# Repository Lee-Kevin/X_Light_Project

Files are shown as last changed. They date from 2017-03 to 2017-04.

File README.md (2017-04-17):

# RGBLED_Ligh Controller Hardware Part
For this project, the hardware part is very import, We buy a RGB bulb from Huaqiang North in ShenZhen, it's something just like below picture shows.

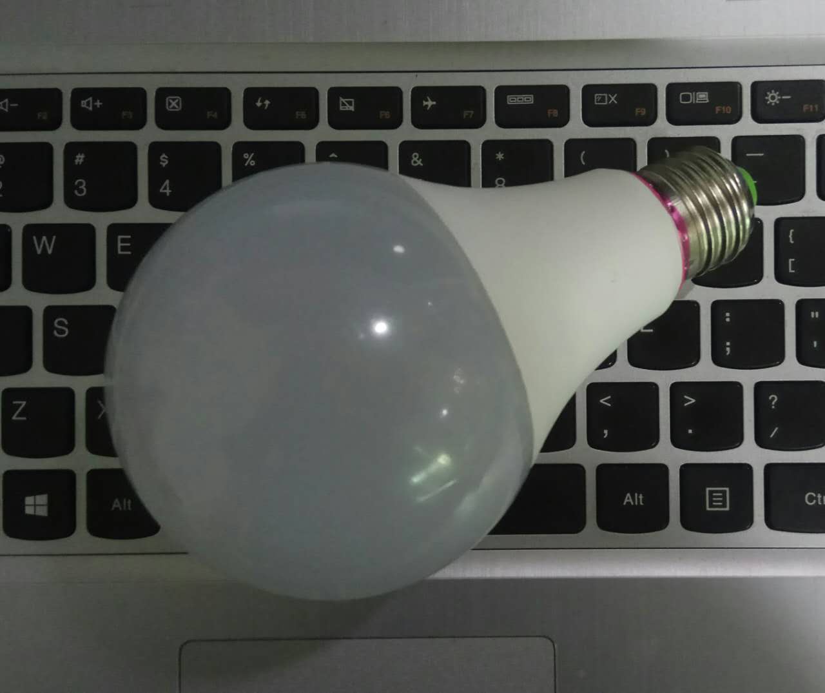
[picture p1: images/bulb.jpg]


The factory version of the bulb is controlled by an IR Remote controller, for this project, we want to control the bulbs by group or control each bulb independently. So we did a special pcb for this bulb. Just like below picture shows.

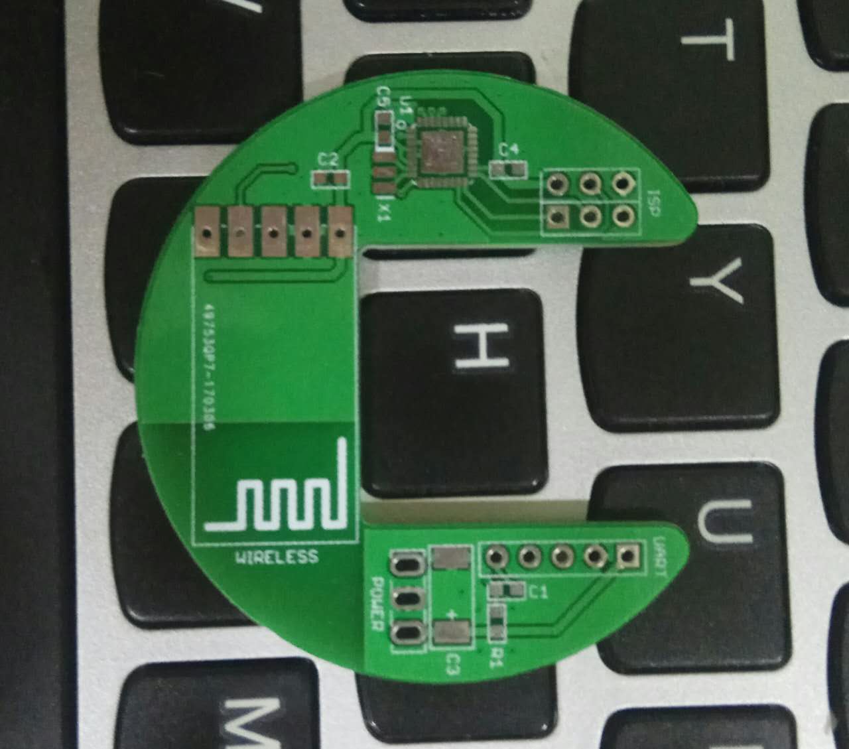
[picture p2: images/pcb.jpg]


I remove the IR reciver from the factory version, and connect the original IR Reciver Pin to the new board, After assembling the bulb is just as shown in the following figure.

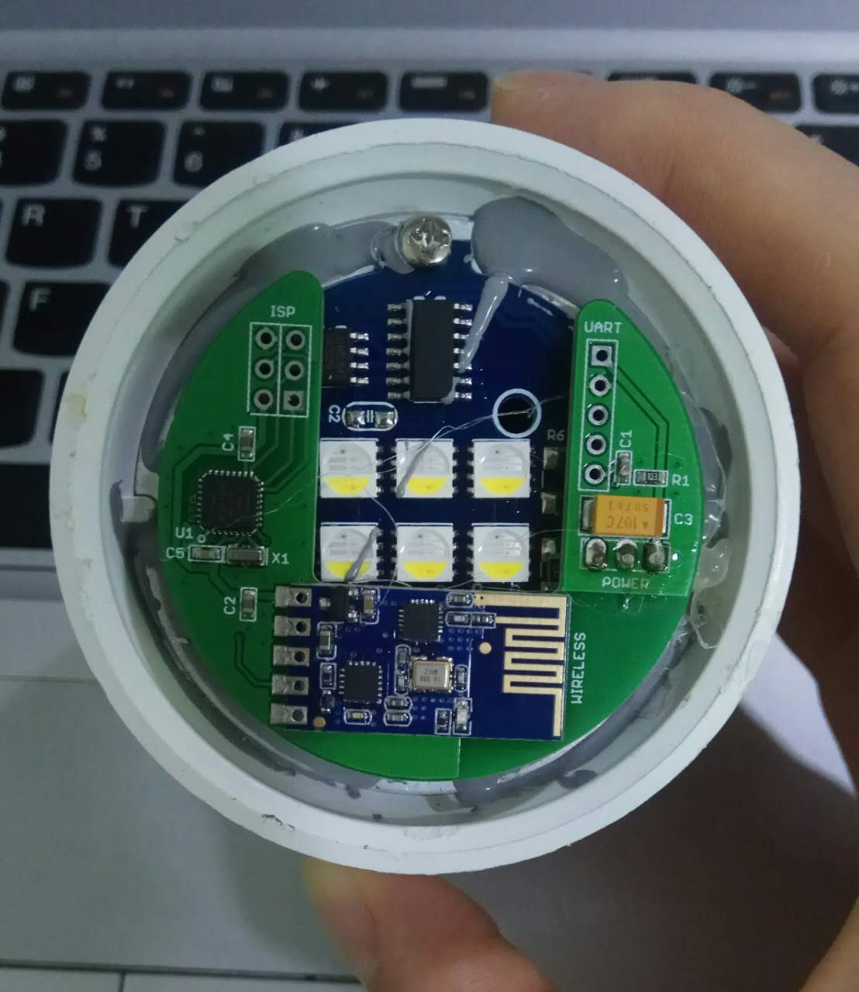
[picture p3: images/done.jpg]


About the pcb and the schematic file, you can click **[here](https://github.com/Lee-Kevin/X_Light_Project/tree/master/Hardware)** to download.

# RGBLED_Ligh Controller Software Part
------
In this project, the software has two part, one is the slave part and the another one is master part.

The slave part will connect to a RGB light, and control the color of the light, the communication between slave and master is wireless/RF.

## Slave Part

This part will recive the command from the master part.

The data frame is:

Head  -  Address  -  Command  -  End

0xAA  -    Addr   -  Command  -  0x55

The Address is a uint8_t value range from 0~255, and 255 is the boardcast address, and 0 is a reserved address.

The Command is something like this:
``` C 
enum LEDstatus {
    led_on            = 0,
    led_off           = 1,
    led_down          = 2,
    led_up            = 3,
    led_red           = 4,
    led_green         = 5,
    led_blue          = 6,
    led_white         = 7,
    led_lightSalmon   = 8,
    led_orangeRed     = 9,
    led_orange        = 10,
    led_yellow        = 11,
    led_paleGreen     = 12,
    led_skyBlue       = 13,
    led_turquoise     = 14,
    led_royalBlue     = 15,
    led_steelBlue     = 16,
    led_purple        = 17,
    led_rebeccapurple = 18,
    led_orchid        = 19,
    led_flash         = 20,
    led_strobe        = 21,
    led_fade          = 22,
    led_smooth        = 23,
    
};
typedef enum LEDstatus ledstatus_t;
ledstatus_t eLEDStatus;
```

The slave part can also set the address via UART, and the command data is like this:

Head  --  Addr  --  Command  -- New Addr  --  END

0xAA  --  0xFF  --   0xFF    --  New Addr --  0x55

Then you can also get the slave address by send the following command:

Head  --  Addr  --  Command  --  END

0xAA  --  0xFF  --   0xFE    --  0x55

Note: the 0xFF is the boardcast addr.

## Master Part

For this system, there can be many master parts to control the light, the only thing that master part need to do is sending commands.

The Master part1 is used for sending command to the slave part, and this part has the following functions.
1. Recive IR command from the IR controller.
2. Recive comand from the computer(just recive data from uart,and send it out via software serial).
3. Change the display mode by a button.
4. Turn ON/OFF the light by a button

More master part to be continued.

## The Light Number 

The following picture shows how the Light is arrranged.

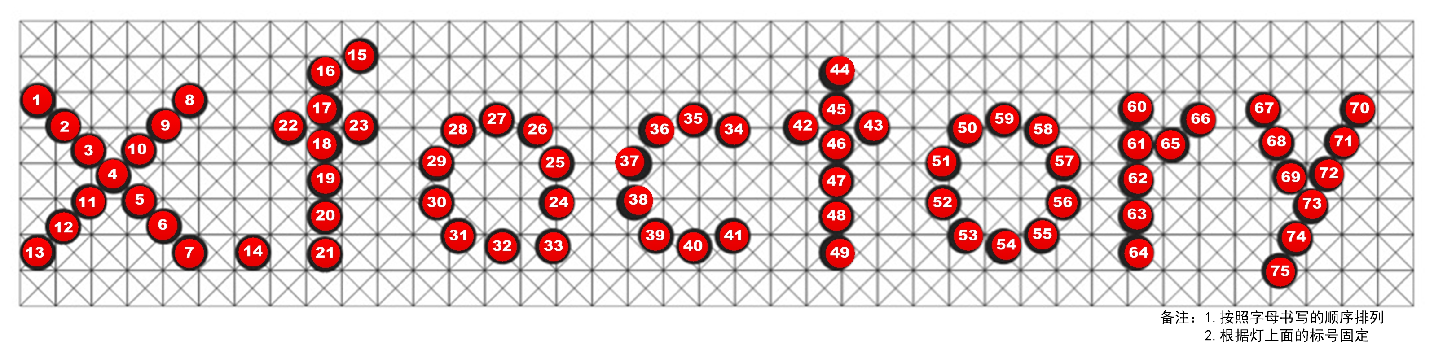
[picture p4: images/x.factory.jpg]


## The finished work

to be continued

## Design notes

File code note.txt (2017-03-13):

=================================================================================================================

1. LightControl_Slave - 201702280948  完成基本程序框架，下一步能够发送指令  9:51 2017/2/28
2. LightControl_Slave - 201702281410  完成指令控制功能，下一步，可以修改地址，并把地址信息写入EEPROM
3. LightControl_Slave - 201703011250  完成software serial的使用，下一步，通过UART可以修改地址 13:39 2017/3/1
4. LightControl_Slave - 201703021253  可以通过串口访问并修改地址，从机程序基本完成 12:54 2017/3/2
5. LightControl_Slave - 201703021726  修正开灯的红外编码 17:26 2017/3/2
6. LightControl_Slave - 201703091451  缩短看门狗喂狗时间至200ms, 添加数据发送临界保护

=================================================================================================================

1. LightControl_Master - 201703021727 完成红外控制广播和串口透传，下一步添加led bar 驱动。
2. LightControl_Master - 201703072201 完成OLED的添加，并显示每一种模式的提示，下一步，增加button, 用button，切换显示模式
3. LightControl_Master - 201703081221 添加了一个button, 用来控制灯的开关，下一步，增加另外另个button，用来切换模式。
4. LightControl_Master - 201703081555 添加了其它两个button，现在出现莫名重启情况，需要研究下原因
5. LightControl_Master - 201703081916 用按键查询方法解决了重启问题，但是在写模式时，关灯指令有时不能响应，需要研究一下原因
6. LightControl_Master - 201703092025 上述问题通过修改从机端代码解决，现在增加了on/off界面，下一步，完善命令发射函数，尽量多写几个模式
7. LightControl_Master - 201703111126 完成4种模式效果

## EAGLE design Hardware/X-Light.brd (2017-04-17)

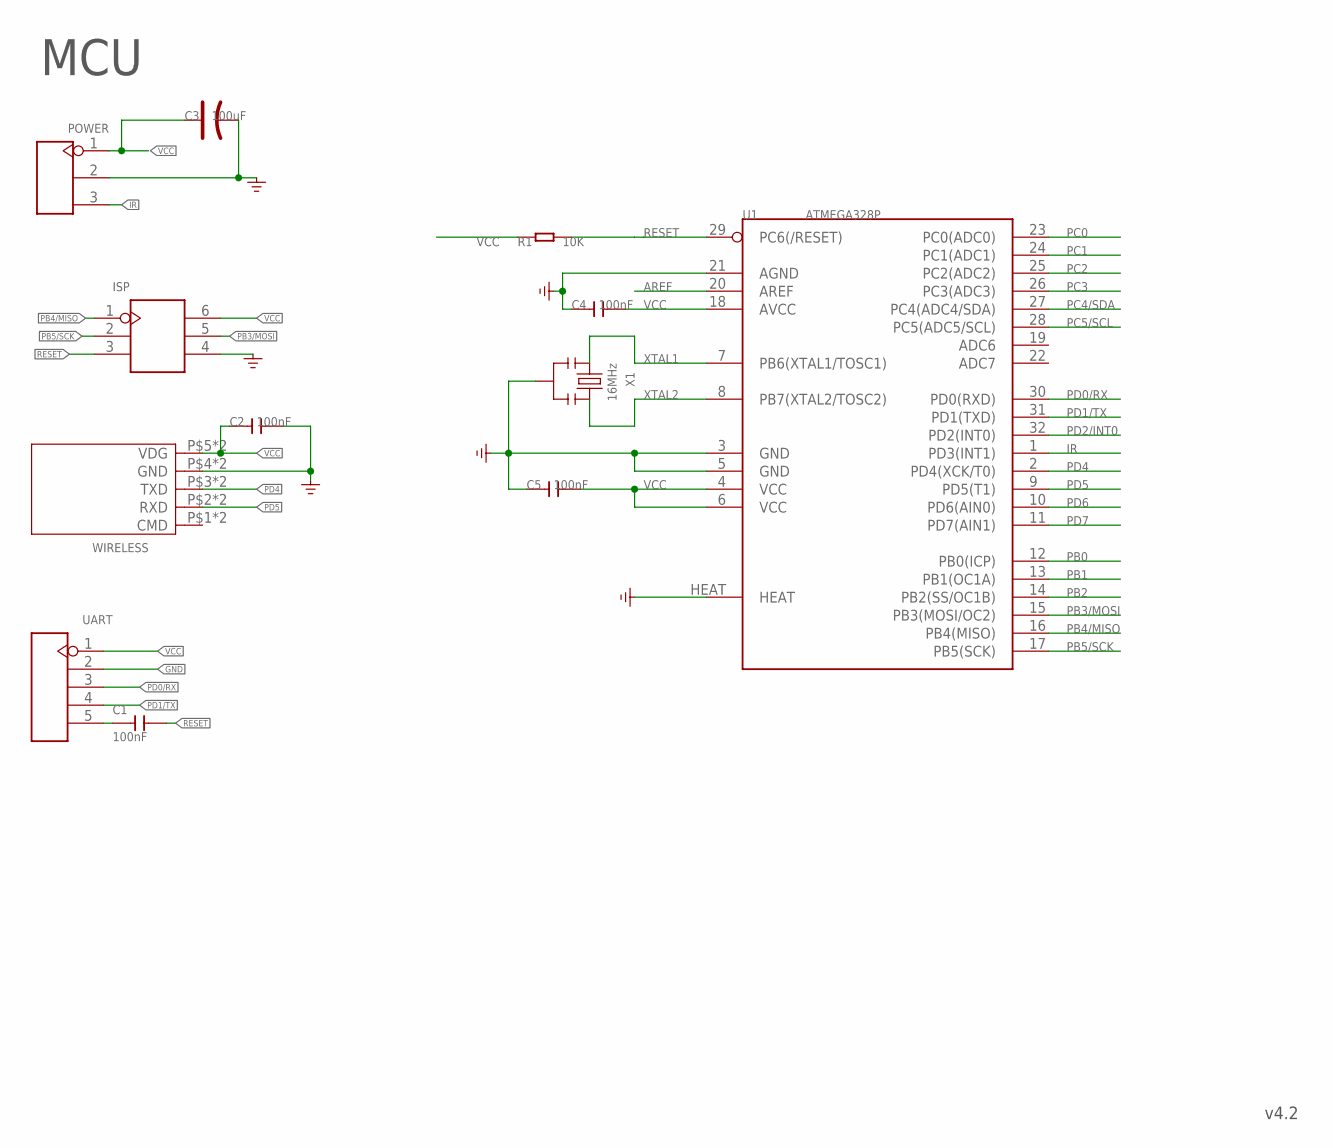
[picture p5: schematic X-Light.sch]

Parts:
C1, C2, C4, C5: 100nF; C0603
C3: 100uF; AVX-C
ISP: HEADER-2X3P-2.54; H2X3-2.54
POWER: HEADER-3P-2.54; H3-2.54
R1: 10K; R0603
U1: ATMEGA328P; MLF32X
UART: HEADER-5P-2.54; H5-2.54
WIRELESS: MOUDLE-5P; 5P-24.2X12.4MM-2.54
X1: 16MHz; 3P-SMD-3.6X1.3

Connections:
AREF: U1.20 (AREF)
GND: C2.2, C3.-, C4.1, C5.1, ISP.4, POWER.2, U1.3 (GND), U1.5 (GND), U1.21 (AGND), U1.HEAT, UART.2, WIRELESS.P4 (GND), WIRELESS.P$4 (GND), X1.2
IR: POWER.3, U1.1 (PD3(INT1))
unnamed: C1.1, UART.5
PB0: U1.12 (PB0(ICP))
PB1: U1.13 (PB1(OC1A))
PB2: U1.14 (PB2(SS/OC1B))
PB3/MOSI: ISP.5, U1.15 (PB3(MOSI/OC2))
PB4/MISO: ISP.1, U1.16 (PB4(MISO))
PB5/SCK: ISP.2, U1.17 (PB5(SCK))
PC0: U1.23 (PC0(ADC0))
PC1: U1.24 (PC1(ADC1))
PC2: U1.25 (PC2(ADC2))
PC3: U1.26 (PC3(ADC3))
PC4/SDA: U1.27 (PC4(ADC4/SDA))
PC5/SCL: U1.28 (PC5(ADC5/SCL))
PD0/RX: U1.30 (PD0(RXD)), UART.3
PD1/TX: U1.31 (PD1(TXD)), UART.4
PD2/INT0: U1.32 (PD2(INT0))
PD4: U1.2 (PD4(XCK/T0)), WIRELESS.P3 (TXD), WIRELESS.P$3 (TXD)
PD5: U1.9 (PD5(T1)), WIRELESS.P2 (RXD), WIRELESS.P$2 (RXD)
PD6: U1.10 (PD6(AIN0))
PD7: U1.11 (PD7(AIN1))
RESET: C1.2, ISP.3, R1.2, U1.29 (PC6(/RESET))
VCC: C2.1, C3.+, C4.2, C5.2, ISP.6, POWER.1, R1.1, U1.4 (VCC), U1.6 (VCC), U1.18 (AVCC), UART.1, WIRELESS.P5 (VDG), WIRELESS.P$5 (VDG)
XTAL1: U1.7 (PB6(XTAL1/TOSC1)), X1.1
XTAL2: U1.8 (PB7(XTAL2/TOSC2)), X1.3

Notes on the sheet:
MCU
v4.2

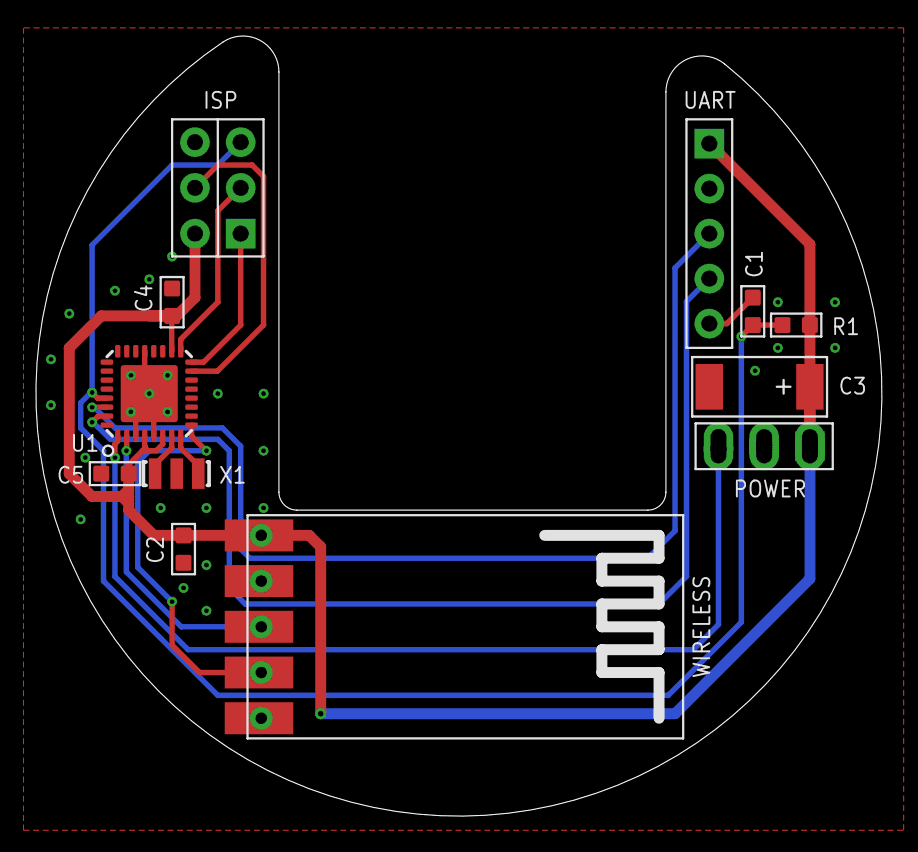
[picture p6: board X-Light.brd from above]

Board: 2 copper layers, 47.0 x 43.3 mm, 12 parts (0 on the bottom side), 14 nets.

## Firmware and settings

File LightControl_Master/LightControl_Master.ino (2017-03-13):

/*
 * Copyright (c) 2015 seeed technology inc.
 * Website    : www.seeed.cc
 * Author     : Jiankai.li @2017/2/27
 * Modified Time: July 2015
 * Description: This is wireless control  light Master Side
 * The MIT License (MIT)
 *
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
 * THE SOFTWARE IS PROVIDED "AS IS", WITHOUT WARRANTY OF ANY KIND, EXPRESS OR
 * IMPLIED, INCLUDING BUT NOT LIMITED TO THE WARRANTIES OF MERCHANTABILITY,
 * FITNESS FOR A PARTICULAR PURPOSE AND NONINFRINGEMENT. IN NO EVENT SHALL THE
 * AUTHORS OR COPYRIGHT HOLDERS BE LIABLE FOR ANY CLAIM, DAMAGES OR OTHER
 * LIABILITY, WHETHER IN AN ACTION OF CONTRACT, TORT OR OTHERWISE, ARISING FROM,
 * OUT OF OR IN CONNECTION WITH THE SOFTWARE OR THE USE OR OTHER DEALINGS IN
 * THE SOFTWARE.
 */

#include <string.h>
#include <IRSendRev.h>
#include <EEPROM.h>
#include <avr/wdt.h>
#include <TimerOne.h>
#include <SoftwareSerial.h>

#include <Wire.h>
#include <SeeedOLED.h>
#include <avr/pgmspace.h>
#include "logo.h"


#define debug   1

// the value of the data frame
// Head  Addr  Command  End
#define HEAD             0xAA
#define END              0x55

#define BoardCastAddress 0xff

#define Switch_PIN       2
#define ModeUP_PIN       7
#define ModeDown_PIN     8

const int pinRecv = 6;

#define LEDCommandNum    24
enum LEDstatus {
    led_on            = 0,
    led_off           = 1,
    led_down          = 2,
    led_up            = 3,
    led_red           = 4,
    led_green         = 5,
    led_blue          = 6,
    led_white         = 7,
    led_lightSalmon   = 8,
    led_orangeRed     = 9,
    led_orange        = 10,
    led_yellow        = 11,
    led_paleGreen     = 12,
    led_skyBlue       = 13,
    led_turquoise     = 14,
    led_royalBlue     = 15,
    led_steelBlue     = 16,
    led_purple        = 17,
    led_rebeccapurple = 18,
    led_orchid        = 19,
    led_flash         = 20,
    led_strobe        = 21,
    led_fade          = 22,
    led_smooth        = 23,
    
};

typedef enum LEDstatus ledstatus_t;
ledstatus_t eLEDStatus;


enum Workstatus {
    light_off           = 0,
    light_IRremote      = 1,
    light_write         = 2,
    light_waterflow     = 3,
    light_random        = 4,
    light_gesture       = 5,
    light_reserved      = 6,
    light_on            = 7,
    
};

typedef enum Workstatus Workstatus_t;
Workstatus_t eWorkstatus;
Workstatus_t last_eWorkstatus;


// // store the univerisal data
// unsigned char CONST_DATA[8] = {9,181,89,11,33,4,0,255};

// store the comand data
unsigned char COMMAND_DATA[24][2] = {
    {224,31},  // led_on
    {96,159},  // led_off
    {32,223},  // led_down
    {160,95},  // led_up
    {144,111}, // led_red
    {16,239},  // led_green
    {80,175},  // led_blue
    {208,47},  // led_white
    {176,79},  // led_lightSalmon
    {168,87},  // led_orangeRed
    {152,103}, // led_orange
    {136,119}, // led_yellow
    {48,207},  // led_paleGreen
    {40,215},  // led_skyBlue
    {24,231},  // led_turquoise
    {8,247},   // led_royalBlue
    {112,143}, // led_steelBlue
    {104,151}, // led_purple
    {88,167},  // led_rebeccapurple
    {72,183},  // led_orchid
    {240,15},  // led_flash
    {232,23},  // led_strobe
    {216,39},  // led_fade
    {200,55},  // led_smooth
};


SoftwareSerial mySerial(4,5); // RX, TX

uint8_t dtaRecv[20];
uint8_t dtaSend[4];
                                                             // ir send connect to D3
                                  
uint8_t Status,MyAddress,cmdStatus;                          // The command status, Address, and temp Command
                               
                                    
void setup()
{
    Serial.begin(9600);
    
    mySerial.begin(9600);                                    // This depend on the wireless module
    
    eWorkstatus = light_reserved;
    
    last_eWorkstatus = eWorkstatus;
    
    wdt_enable(WDTO_2S);
    Timer1.initialize(200000);                               // set a timer of length 1000000 microseconds 1 second
    Timer1.attachInterrupt( timerIsrFeedFog );               // attach the service routine here
    wdt_reset();
    pinMode(Switch_PIN, INPUT_PULLUP);
    pinMode(ModeUP_PIN,INPUT_PULLUP);
    pinMode(ModeDown_PIN,INPUT_PULLUP);
    dtaSend[0] = HEAD;
    dtaSend[1] = BoardCastAddress;
    dtaSend[3] = END;
    
    IR.Init(pinRecv);
    // init the oled
    Wire.begin();	
    SeeedOled.init();                                        //initialze SEEED OLED display
    SeeedOled.clearDisplay();                                // clear the screen and set start position to top left corner
    SeeedOled.deactivateScroll(); 
    SeeedOled.drawBitmap((unsigned char*) SeeedLogo,1024);   // 1024 = 128 Pixels * 64 Pixels / 8
    // SeeedOled.drawBitmap((unsigned char*) SeeedOFF,1024);   // 1024 = 128 Pixels * 64 Pixels / 8
    Serial.println("System init ");
    
}

void loop()
{
    
    IREvent(); 
    // Do the action here
    switch (eWorkstatus) {
       
    case light_off:
        break;
    case light_on:
        break;        
    case light_IRremote:  // Mode 1
        break;
    case light_write:     // Mode 2
        lightWrite((uint8_t)light_write,250);
        break;
    case light_waterflow: // Mode 3
        sendCommand(BoardCastAddress,led_on);
        lightWrite((uint8_t)light_waterflow,250);
        break;
    case light_random:
        sendCommand(BoardCastAddress,led_on);
        lightRandom(500);
        break;
    default:
        break;
    }
    
    // Update the display
    IfButtonClick();
    if (last_eWorkstatus != eWorkstatus) {
        displayStatus(eWorkstatus);
        last_eWorkstatus = eWorkstatus;
    }
}

// Send the data to the slave part
void sendData() {
    for (int j=0; j<4; j++) {
        mySerial.write(dtaSend[j]);
    }
}

// Send the command 
void sendCommand(uint8_t addr,uint8_t command) {
    dtaSend[1] = addr;
    dtaSend[2] = command;
    sendData();
}

void lightWrite(uint8_t flag, uint8_t delay) {
    static unsigned long currentMillis ;
    static unsigned long previousMillis = 0;
    uint8_t interval = delay;  
    for (int i=1; i<=78;) {
        currentMillis = millis();
        if (currentMillis - previousMillis >= interval) {
            previousMillis = currentMillis;
            // Serial.println("================previousMillis==================");
            // Serial.println(previousMillis);
            if(flag == (uint8_t)light_write) {
                if(i>4) {
                    sendCommand(i-4,led_off);
                    sendCommand(i,led_on);
                } else {
                    sendCommand(i,led_on);
                }
                i++;
            } else if(flag == (uint8_t)light_waterflow) {
                sendCommand(i,led_fade);
                i++;
            }
        }
        if (IfButtonClick() || IREvent()) {
            Serial.println("Break the light write");
            break;
        }
    }
}

void lightRandom(uint16_t delay) {
    static unsigned long currentMillis ;
    static unsigned long previousMillis = 0;
    boolean flag = false;
    uint16_t interval = delay;  
    for (int i=1; i<=5;) {
        currentMillis = millis();
        if (currentMillis - previousMillis >= interval) {
            previousMillis = currentMillis;
            for(uint8_t j=1; j<=75; j++) {
                sendCommand(j,random(4,23));
                // Serial.println("Change the light");
                if (IfButtonClick() || IREvent()) {
                    // Serial.println("Break the light write");
                    flag = true;
                    break;
                }
            }
            i++;
        }
        if (IfButtonClick() || IREvent() || flag) {
            Serial.println("Break the light write");
            break;
        }
    }
}

// This is the function to judge if the Mode control button is pressed.
uint8_t IfButtonClick() {
    static uint8_t lastButtonState =  HIGH;
    static uint8_t buttonState = HIGH;
    static uint8_t lastButtonState2 =  HIGH;
    static uint8_t buttonState2 = HIGH;
    
    static uint8_t lastButtonState3 =  HIGH;
    static uint8_t buttonState3 = HIGH;
    static unsigned long lastDebounceTime = 0;  // the last time the output pin was toggled
    static unsigned long debounceDelay = 50;    // the debounce time; increase if the output flickers
    static boolean flag = false;
 
    uint8_t reading = digitalRead(ModeUP_PIN);

    if (reading != lastButtonState) {
        lastDebounceTime = millis();
    }
    if ((millis() - lastDebounceTime) > debounceDelay) {
        if (reading != buttonState) {
            buttonState = reading;
            if (buttonState == HIGH) {
                Serial.println("The Button up Pressed");
                uint8_t status = (uint8_t)eWorkstatus;
                if(++status >= (uint8_t)light_random ) {
                    eWorkstatus = light_random;
                } else {
                    eWorkstatus = (Workstatus_t)status;
                }
                return 1;
            }
        }
    }
    
    uint8_t reading2 = digitalRead(ModeDown_PIN);
    if (reading2 != lastButtonState2) {
        lastDebounceTime = millis();
    }
    if ((millis() - lastDebounceTime) > debounceDelay) {
        if (reading2 != buttonState2) {
            buttonState2 = reading2;
            if (buttonState2 == HIGH) {
                Serial.println("The Button DOWN Pressed");
                uint8_t status = (uint8_t)eWorkstatus;
                if (status >= light_random) {
                    status = light_random;
                }
                if(--status <= (uint8_t)light_IRremote ) {
                    eWorkstatus = light_IRremote;
                } else {
                    eWorkstatus = (Workstatus_t)status;
                }
                return 2;
            }
        }
    }
    
    uint8_t reading3 = digitalRead(Switch_PIN);
    if (reading3 != lastButtonState3) {
        lastDebounceTime = millis();
    }
    if ((millis() - lastDebounceTime) > debounceDelay) {
        if (reading3 != buttonState3) {
            buttonState3 = reading3;
            if (buttonState3 == HIGH) {
                Serial.println("The Button Switch Pressed");
                if(flag == true) {
                    flag = false;
                    eWorkstatus = light_off;
                    sendCommand(BoardCastAddress,led_off);
                    sendCommand(BoardCastAddress,led_off);
                } else {
                    flag = true;
                    eWorkstatus = light_on;
                    sendCommand(BoardCastAddress,led_on);
                    sendCommand(BoardCastAddress,led_on);
                }
                return 3;
            }
        }
    }
    lastButtonState3 = reading3;
    lastButtonState2 = reading2;
    lastButtonState = reading;
    return 0;
}

// This is the display function.
void displayStatus(Workstatus_t status) {
    switch(status) {
    case light_off:
        SeeedOled.clearDisplay();
        SeeedOled.deactivateScroll(); 
        SeeedOled.drawBitmap((unsigned char*) SeeedOFF,1024);   // 1024 = 128 Pixels * 64 Pixels / 8
        break;        
    case light_on:
        SeeedOled.clearDisplay();
        SeeedOled.deactivateScroll(); 
        SeeedOled.drawBitmap((unsigned char*) SeeedON,1024);   // 1024 = 128 Pixels * 64 Pixels / 8
        break;    
    case light_IRremote:
        SeeedOled.clearDisplay();
        SeeedOled.deactivateScroll(); 
        SeeedOled.drawBitmap((unsigned char*) mode1,1024);   // 1024 = 128 Pixels * 64 Pixels / 8
        SeeedOled.setTextXY(7,0);          //Set the cursor to Xth Page, Yth Column 
        SeeedOled.setPageMode();
        SeeedOled.putString("Controller mode"); //Print the String
        SeeedOled.setHorizontalScrollProperties(Scroll_Left,7,7,Scroll_5Frames); //Set Scrolling properties to Scroll Left
        SeeedOled.activateScroll();   
        break;
    case light_write:
        SeeedOled.clearDisplay();  
        SeeedOled.deactivateScroll(); 
        SeeedOled.drawBitmap((unsigned char*) mode2,1024);   // 1024 = 128 Pixels * 64 Pixels / 8
        
        SeeedOled.setTextXY(7,0);          //Set the cursor to Xth Page, Yth Column 
        SeeedOled.setPageMode();
        SeeedOled.putString("Write mode"); //Print the String
        SeeedOled.setHorizontalScrollProperties(Scroll_Left,7,7,Scroll_5Frames); //Set Scrolling properties to Scroll Left
        SeeedOled.activateScroll();   
        break;    
    case light_waterflow:
        SeeedOled.clearDisplay(); 
        SeeedOled.deactivateScroll(); 
        SeeedOled.drawBitmap((unsigned char*) mode3,1024);   // 1024 = 128 Pixels * 64 Pixels / 8
        SeeedOled.setTextXY(7,0);          //Set the cursor to Xth Page, Yth Column 
        SeeedOled.setPageMode();
        SeeedOled.putString("WaterFlow mode"); //Print the String
        SeeedOled.setHorizontalScrollProperties(Scroll_Left,7,7,Scroll_5Frames); //Set Scrolling properties to Scroll Left
        SeeedOled.activateScroll();   
        break;    
    case light_random:
        SeeedOled.clearDisplay(); 
        SeeedOled.deactivateScroll(); 
        SeeedOled.drawBitmap((unsigned char*) mode4,1024);   // 1024 = 128 Pixels * 64 Pixels / 8
        SeeedOled.setTextXY(7,0);          //Set the cursor to Xth Page, Yth Column 
        SeeedOled.setPageMode();
        SeeedOled.putString("Random mode"); //Print the String
        SeeedOled.setHorizontalScrollProperties(Scroll_Left,7,7,Scroll_5Frames); //Set Scrolling properties to Scroll Left
        SeeedOled.activateScroll();   
        break;    
    default:
        SeeedOled.clearDisplay();
        SeeedOled.deactivateScroll(); 
        SeeedOled.drawBitmap((unsigned char*) SeeedLogo,1024);   // 1024 = 128 Pixels * 64 Pixels / 8
        break;
    }
    
}


// This is used for wireless communication
// The Frame data is 
// Head  Address  command  End
// 0xAA  0xFF     0xFF     0x55


void serialEvent() {
    while (Serial.available()) { 
        mySerial.write(Serial.read());
    }    
}

// This is used for IR control all of the light

uint8_t IREvent() {
    if (IR.IsDta()) {
        IR.Recv(dtaRecv);
        #if debug
        for (int j=8; j<10;j++) {
             Serial.print(dtaRecv[j]);
        }
        Serial.println("==========Recive the IR=========");
        #endif
        for (int i=0; i<24;i++) {
            if (memcmp(COMMAND_DATA[i],&dtaRecv[8],2) == 0) {
                Serial.print("Recive the Command index is: ");
                Serial.println(i);
                sendCommand(BoardCastAddress,i);
                sendCommand(BoardCastAddress,i);
                i==1?eWorkstatus = light_reserved:eWorkstatus = light_IRremote;
                return 1;
            }
             
        }
    }
    return 0;
}

void timerIsrFeedFog()
{   
    wdt_reset();
}

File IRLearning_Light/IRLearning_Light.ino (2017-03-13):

/*
 * Copyright (c) 2015 seeed technology inc.
 * Website    : www.seeed.cc
 * Author     : Seeed
 * Modified Time: July 2015
 * Description: Must connect the IR send pins to D3 for this demo. You can use Infrared Emitter combination with Infrared Receiver.
 *				You can see the remote control's infrared data that received through Infrared Receiver, then write the received 
 *				infrared data into send.ino and downloaded to the board with Infrared Emitter Grove, so you can send the same data  
 *				with remote control's button.
 * 				
 * The MIT License (MIT)
 *
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
 * THE SOFTWARE IS PROVIDED "AS IS", WITHOUT WARRANTY OF ANY KIND, EXPRESS OR
 * IMPLIED, INCLUDING BUT NOT LIMITED TO THE WARRANTIES OF MERCHANTABILITY,
 * FITNESS FOR A PARTICULAR PURPOSE AND NONINFRINGEMENT. IN NO EVENT SHALL THE
 * AUTHORS OR COPYRIGHT HOLDERS BE LIABLE FOR ANY CLAIM, DAMAGES OR OTHER
 * LIABILITY, WHETHER IN AN ACTION OF CONTRACT, TORT OR OTHERWISE, ARISING FROM,
 * OUT OF OR IN CONNECTION WITH THE SOFTWARE OR THE USE OR OTHER DEALINGS IN
 * THE SOFTWARE.
 */

#include <IRSendRev.h>

#define BIT_LEN         0
#define BIT_START_H     1
#define BIT_START_L     2
#define BIT_DATA_H      3
#define BIT_DATA_L      4
#define BIT_DATA_LEN    5
#define BIT_DATA        6

const int ir_freq = 38;                 // 38k

unsigned char dta[20];

const int pinRecv = 5;              // ir receiver connect to D2

void setup()
{
    IR.Init(pinRecv);
    Serial.begin(115200);
    Serial.println("init over");
}

void loop()
{

	if(IR.IsDta())                  // get IR data
    {
        IR.Recv(dta);               // receive data to dta

        Serial.println("+------------------------------------------------------+");
		Serial.print("LEN = ");
        Serial.println(dta[BIT_LEN]);
        Serial.print("START_H: ");
        Serial.print(dta[BIT_START_H]);
        Serial.print("\tSTART_L: ");
        Serial.println(dta[BIT_START_L]);
        
        Serial.print("DATA_H: ");
        Serial.print(dta[BIT_DATA_H]);
        Serial.print("\tDATA_L: ");
        Serial.println(dta[BIT_DATA_L]);
        
        Serial.print("\r\nDATA_LEN = ");
        Serial.println(dta[BIT_DATA_LEN]);
        
		Serial.print("DATA: ");
        for(int i=0; i<dta[BIT_DATA_LEN]; i++)
        {
            Serial.print("0x");
            Serial.print(dta[i+BIT_DATA], HEX);
            Serial.print("\t");
        }
        Serial.println();
		
		Serial.print("DATA: ");
        for(int i=0; i<dta[BIT_DATA_LEN]; i++)
        {
            Serial.print(dta[i+BIT_DATA], DEC);
            Serial.print("\t");
        }
        Serial.println();
        Serial.println("+------------------------------------------------------+\r\n\r\n");
		
		delay(200);
       IR.Send(dta, ir_freq);
       Serial.println("Send the command sucessfully");
       // delay(1500);
	   
	   Serial.println("Waiting for command");
    }
	// Serial.println("------------------Still waiting-----------------------");
	// delay(1000);
	

}
